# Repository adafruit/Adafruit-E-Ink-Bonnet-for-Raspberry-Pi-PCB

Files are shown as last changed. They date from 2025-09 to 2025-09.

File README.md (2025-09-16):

## Adafruit E-Ink Bonnet for Raspberry Pi - 24-pin E-Paper Displays PCB

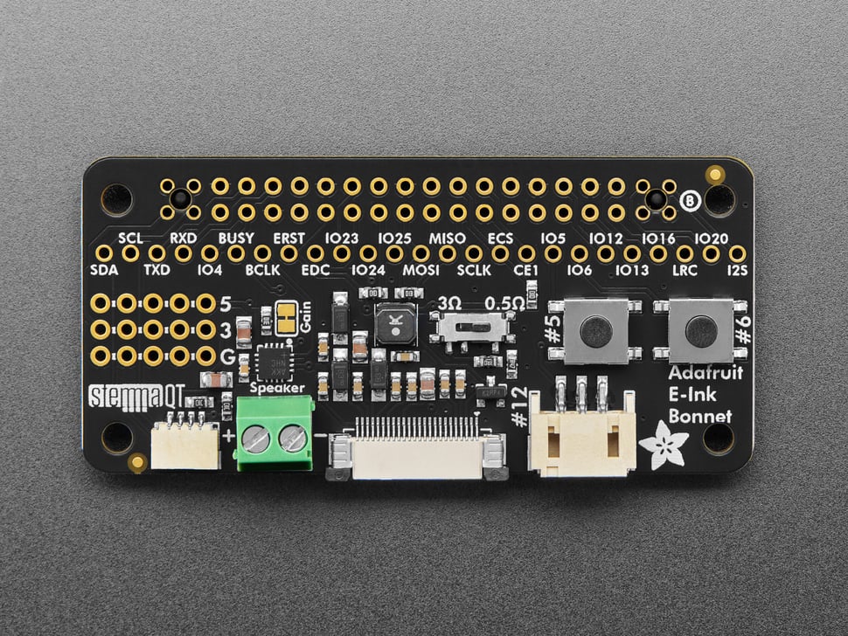
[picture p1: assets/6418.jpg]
<a href="http://www.adafruit.com/products/6418"><br/>
Click here to purchase one from the Adafruit shop</a>

PCB files for the Adafruit E-Ink Bonnet for Raspberry Pi - 24-pin E-Paper Displays. 

Format is EagleCAD schematic and board layout
* https://www.adafruit.com/product/6418

### Description

Easy e-paper finally comes to Raspberry Pi, with this bonnet that's designed to make it a breeze to add any 'standard' pinout 24-pin flex-connector E-Ink display. This add-on handles all the extra components needed to make E-Paper interfacing easy for Pi and Pi-compatible boards. We even include extras like two user buttons, Stemma QT I2C port, and a 3W I2S speaker so you can also have audio playback. Insert your favorite E-Paper display to the connector and you'll have a powerful Linux-powered display for your desk or wall.

Chances are you've seen one of those new-fangled 'e-readers' like the Kindle or Nook. They have gigantic electronic paper 'static' displays - that means the image stays on the display even when power is completely disconnected. The image is also high contrast and very daylight readable. It really does look just like printed paper!

<b>Please note that this does NOT come with the raw display itself</b> - [we stock a wide variety of bare displays](https://www.adafruit.com/product/6396) that will work great. Don't forget to verify that each display needs driver code to match the driver chip. For displays we sell, [we have examples in our E-Ink Python library you can use to craft your own project.](https://github.com/adafruit/Adafruit_CircuitPython_EPD) Often times the E-Paper display has a short cable, in which case [we suggest one of our extender cables.](https://www.adafruit.com/product/4230)

<b>Comes completely pre-assembled and tested</b> so you can plug it in and install our Python code! <b>Works with any Raspberry Pi computer that has a 2x20 connector</b>, such as the Pi B+, Pi 2, Pi 3, Pi 4, Pi 5, and Pi Zero (and any others that have a 2x20 connector!) For installing on Pi's where you need to clear a case or you don't want it against the board, [grab a 2x20 socket riser.](https://www.adafruit.com/product/4079)

Since we had some space on the bonnet we added a [MAX98357 3W 4-8Ω speaker driver](https://www.adafruit.com/product/3006) which has digital I2S input for great sounding audio. This makes it easy to add audio alerts and feedback to your E-Paper projects. [Note you'll have to add a 4-8Ω speaker to the terminal blocks.](https://www.adafruit.com/product/4445)

[On the bottom, we have a Qwiic/STEMMA QT connector for I2C sensors and devices so you can plug and play any of our STEMMA QT devices.](https://www.adafruit.com/?q=stemma%20qt)

<b>To summarize, you will probably want some accessories to build a full project:</b>

* A matching 'bare' E-Paper display with standard 24-pin connector [we stock a wide variety of bare displays here](https://www.adafruit.com/product/6396)
* [One of our extender cables](https://www.adafruit.com/product/4230) so you have plenty of maneuvering room
* [A 4-8Ω speaker](https://www.adafruit.com/product/4445) if you want to use the onboard amplifier
* And of course a Raspberry Pi or other 2x20-connector'd single-board Linux computer!

### License

Adafruit invests time and resources providing this open source design, please support Adafruit and open-source hardware by purchasing products from [Adafruit](https://www.adafruit.com)!

Designed by Limor Fried/Ladyada for Adafruit Industries.

Creative Commons Attribution/Share-Alike, all text above must be included in any redistribution. 
See license.txt for additional details.

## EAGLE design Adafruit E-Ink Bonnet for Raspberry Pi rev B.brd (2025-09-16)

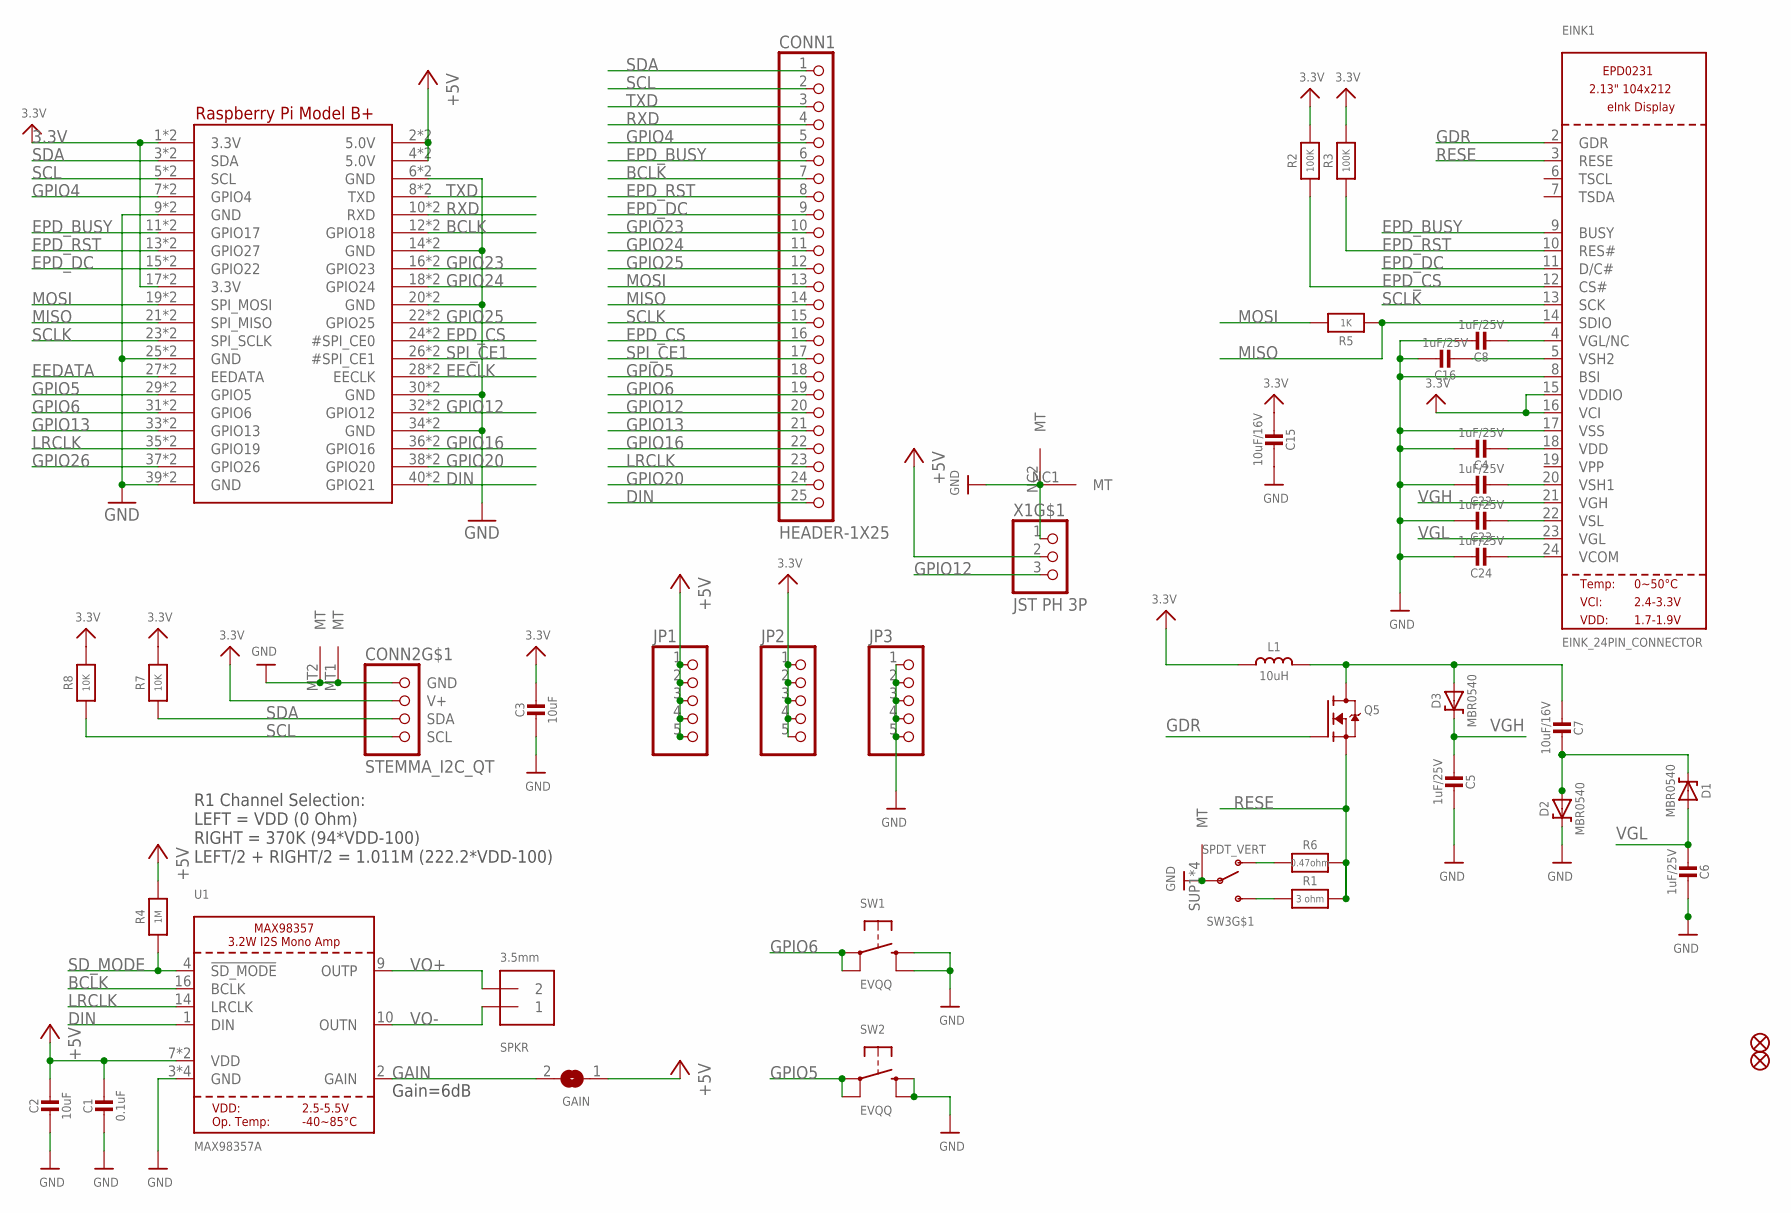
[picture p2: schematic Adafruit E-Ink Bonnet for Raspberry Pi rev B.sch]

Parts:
C1: 0.1uF; 0603-NO
C2, C3: 10uF; 0805-NO
C4, C5, C6, C8, C16, C22, C23, C24: 1uF/25V; 0603-NO
C7, C15: 10uF/16V; 0805-NO
CONN1: HEADER-1X25; 1X25_ROUND_70MIL
CONN2: STEMMA_I2C_QT; JST_SH4
D1, D2, D3: MBR0540; SOD-123
EINK1: EINK_24PIN_CONNECTOR; EINK_24PIN
FID2, FID3: FIDUCIAL_1MM
GAIN: SOLDERJUMPERCLOSED; SOLDERJUMPER_CLOSEDWIRE
JP1, JP2, JP3: HEADER-1X576MIL; 1X05_ROUND_76
L1: 10uH; INDUCTOR_4X4MM_NR401
Q5: IRLML0100; SOT23-3
R1: 3 ohm; 0603-NO
R2, R3: 100K; 0603-NO
R4: 1M; 0603-NO
R5: 1K; 0603-NO
R6: 0.47ohm; 0603-NO
R7, R8: 10K; 0603-NO
RPI1: RASPBERRYPI_BPLUS_BONNET_THMSMT; PI_BONNET_THMSMT
SPKR: 3.5mm; TERMBLOCK_1X2-3.5MM
SW1, SW2: EVQQ; 6MMX6MM_TACTILE_SMT
SW3: SPDT_VERT; SPDT_SMT_SSSS811101
U1: MAX98357A; QFN16_3MM
X1: JST PH 3P; JSTPH3

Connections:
3.3V: C3.1, C15.2, CONN2.2 (V+), EINK1.15 (VDDIO), EINK1.16 (VCI), JP2.1, JP2.2, JP2.3, JP2.4, JP2.5, L1.P$2 (2), R2.2, R3.2, R7.1, R8.1, RPI1.1 (3.3V), RPI1.17 (3.3V), RPI1.S1 (3.3V), RPI1.S17 (3.3V)
+5V: C1.1, C2.1, GAIN.1, JP1.1, JP1.2, JP1.3, JP1.4, JP1.5, R4.2, RPI1.2 (5.0V), RPI1.4 (5.0V), RPI1.S2 (5.0V), RPI1.S4 (5.0V), U1.7 (VDD), U1.8 (VDD), X1.2
BCLK: CONN1.7, RPI1.12 (GPIO18), RPI1.S12 (GPIO18), U1.16 (BCLK)
DIN: CONN1.25, RPI1.40 (GPIO21), RPI1.S40 (GPIO21), U1.1 (DIN)
EECLK: RPI1.28 (EECLK), RPI1.S28 (EECLK)
EEDATA: RPI1.27 (EEDATA), RPI1.S27 (EEDATA)
EPD_BUSY: CONN1.6, EINK1.9 (BUSY), RPI1.11 (GPIO17), RPI1.S11 (GPIO17)
EPD_CS: CONN1.16, EINK1.12 (CS#), R2.1, RPI1.24 (#SPI_CE0), RPI1.S24 (#SPI_CE0)
EPD_DC: CONN1.9, EINK1.11 (D/C#), RPI1.15 (GPIO22), RPI1.S15 (GPIO22)
EPD_RST: CONN1.8, EINK1.10 (RES#), R3.1, RPI1.13 (GPIO27), RPI1.S13 (GPIO27)
GAIN: GAIN.2, U1.2 (GAIN)
GDR: EINK1.2 (GDR), Q5.1 (G)
GND: C1.2, C2.2, C3.2, C4.1, C5.2, C6.2, C8.1, C15.1, C16.1, C22.1, C23.1, C24.1, CONN2.1 (GND), CONN2.MT1 (MT), CONN2.MT2 (MT), D2.C, EINK1.8 (BSI), EINK1.17 (VSS), JP3.1, JP3.2, JP3.3, JP3.4, JP3.5, RPI1.6 (GND), RPI1.9 (GND), RPI1.14 (GND), RPI1.20 (GND), RPI1.25 (GND), RPI1.30 (GND), RPI1.34 (GND), RPI1.39 (GND), RPI1.S6 (GND), RPI1.S9 (GND), RPI1.S14 (GND), RPI1.S20 (GND), RPI1.S25 (GND), RPI1.S30 (GND), RPI1.S34 (GND), RPI1.S39 (GND), SW1.B (S), SW1.B' (S1), SW2.B (S), SW2.B' (S1), SW3.B, SW3.SUP1 (MT), SW3.SUP2 (MT), SW3.SUP3 (MT), SW3.SUP4 (MT), U1.3 (GND), U1.11 (GND), U1.15 (GND), U1.THERMAL (GND), X1.1, X1.NC1 (MT), X1.NC2 (MT)
GPIO4: CONN1.5, RPI1.7 (GPIO4), RPI1.S7 (GPIO4)
GPIO5: CONN1.18, RPI1.29 (GPIO5), RPI1.S29 (GPIO5), SW2.A, SW2.A' (P1)
GPIO6: CONN1.19, RPI1.31 (GPIO6), RPI1.S31 (GPIO6), SW1.A, SW1.A' (P1)
GPIO12: CONN1.20, RPI1.32 (GPIO12), RPI1.S32 (GPIO12), X1.3
GPIO13: CONN1.21, RPI1.33 (GPIO13), RPI1.S33 (GPIO13)
GPIO16: CONN1.22, RPI1.36 (GPIO16), RPI1.S36 (GPIO16)
GPIO20: CONN1.24, RPI1.38 (GPIO20), RPI1.S38 (GPIO20)
GPIO23: CONN1.10, RPI1.16 (GPIO23), RPI1.S16 (GPIO23)
GPIO24: CONN1.11, RPI1.18 (GPIO24), RPI1.S18 (GPIO24)
GPIO25: CONN1.12, RPI1.22 (GPIO25), RPI1.S22 (GPIO25)
GPIO26: RPI1.37 (GPIO26), RPI1.S37 (GPIO26)
LRCLK: CONN1.23, RPI1.35 (GPIO19), RPI1.S35 (GPIO19), U1.14 (LRCLK)
MISO: CONN1.14, EINK1.14 (SDIO), R5.1, RPI1.21 (SPI_MISO), RPI1.S21 (SPI_MISO)
MOSI: CONN1.13, R5.2, RPI1.19 (SPI_MOSI), RPI1.S19 (SPI_MOSI)
unnamed: R1.2, SW3.C (S)
unnamed: C7.2, D1.C, D2.A
unnamed: C7.1, D3.A, L1.P$1 (1), Q5.3 (D)
unnamed: C16.2, EINK1.5 (VSH2)
unnamed: C4.2, EINK1.18 (VDD)
unnamed: C22.2, EINK1.20 (VSH1)
unnamed: R6.2, SW3.A (O)
unnamed: C8.2, EINK1.4 (VGL/NC)
unnamed: C23.2, EINK1.22 (VSL)
unnamed: C24.2, EINK1.24 (VCOM)
RESE: EINK1.3 (RESE), Q5.2 (S), R1.1, R6.1
RXD: CONN1.4, RPI1.10 (RXD), RPI1.S10 (RXD)
SCL: CONN1.2, CONN2.4 (SCL), R8.2, RPI1.5 (SCL), RPI1.S5 (SCL)
SCLK: CONN1.15, EINK1.13 (SCK), RPI1.23 (SPI_SCLK), RPI1.S23 (SPI_SCLK)
SDA: CONN1.1, CONN2.3 (SDA), R7.2, RPI1.3 (SDA), RPI1.S3 (SDA)
SD_MODE: R4.1, U1.4 (!SD_MODE)
SPI_CE1: CONN1.17, RPI1.26 (#SPI_CE1), RPI1.S26 (#SPI_CE1)
TXD: CONN1.3, RPI1.8 (TXD), RPI1.S8 (TXD)
VGH: C5.1, D3.C, EINK1.21 (VGH)
VGL: C6.1, D1.A, EINK1.23 (VGL)
VO+: SPKR.2, U1.9 (OUTP)
VO-: SPKR.1, U1.10 (OUTN)

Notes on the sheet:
R1 Channel Selection: LEFT = VDD (0 Ohm) RIGHT = 370K (94*VDD-100) LEFT/2 + RIGHT/2 = 1.011M (222.2*VDD-100)
Gain=6dB

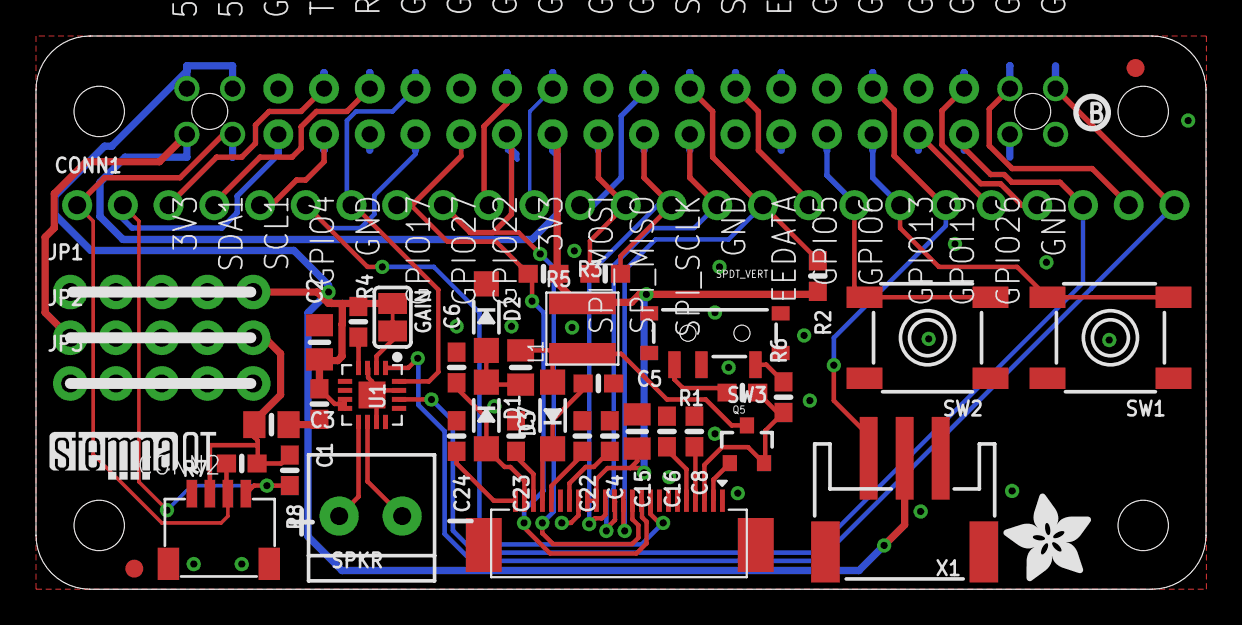
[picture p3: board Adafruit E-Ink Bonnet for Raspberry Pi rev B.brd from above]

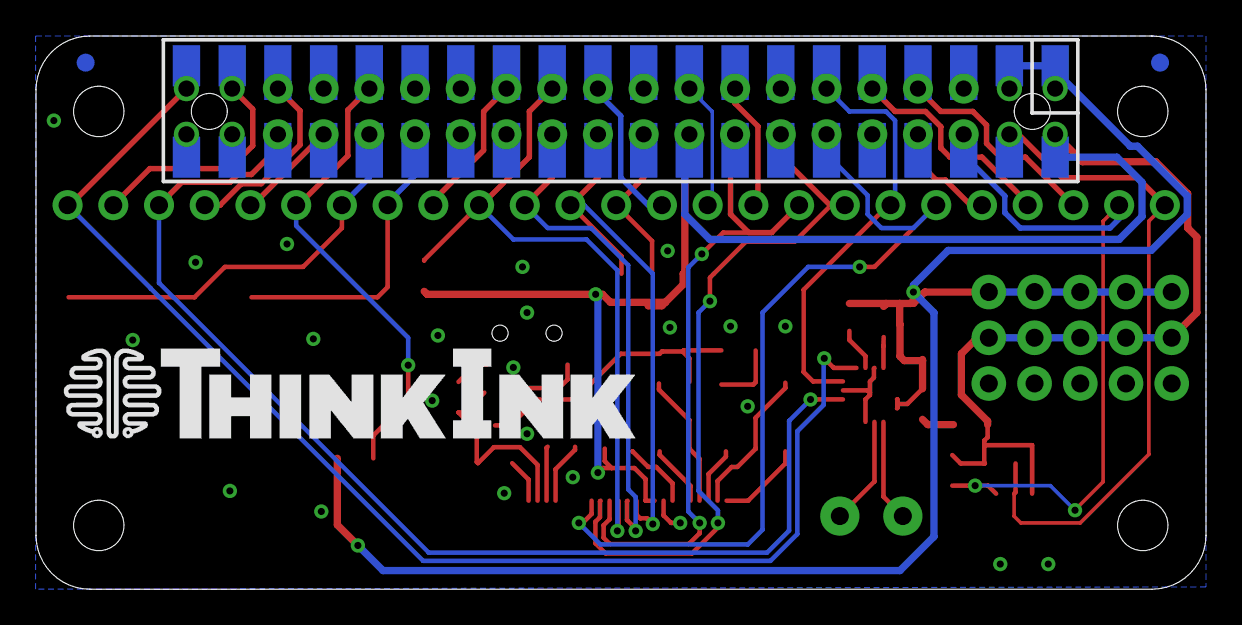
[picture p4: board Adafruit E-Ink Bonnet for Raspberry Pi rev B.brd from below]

Board: 2 copper layers, 65.0 x 30.7 mm, 85 parts (4 on the bottom side), 49 nets.

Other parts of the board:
E$1: THINKINK_1.25IN
PLABEL0: PLABEL0
PLABEL1: PLABEL1
PLABEL2: PLABEL2
PLABEL3: PLABEL3
PLABEL4: PLABEL4
PLABEL5: PLABEL5
PLABEL6: PLABEL6
PLABEL7: PLABEL7
PLABEL8: PLABEL8
PLABEL9: PLABEL9
PLABEL10: PLABEL10
PLABEL11: PLABEL11
PLABEL12: PLABEL12
PLABEL13: PLABEL13
PLABEL14: PLABEL14
PLABEL15: PLABEL15
PLABEL16: PLABEL16
PLABEL17: PLABEL17
PLABEL18: PLABEL18
PLABEL19: PLABEL19
PLABEL20: PLABEL20
PLABEL21: PLABEL21
PLABEL22: PLABEL22
PLABEL23: PLABEL23
PLABEL24: PLABEL24
PLABEL25: PLABEL25
PLABEL26: PLABEL26
PLABEL27: PLABEL27
PLABEL28: PLABEL28
PLABEL29: PLABEL29
PLABEL30: PLABEL30
PLABEL31: PLABEL31
PLABEL32: PLABEL32
PLABEL33: PLABEL33
PLABEL34: PLABEL34
PLABEL35: PLABEL35
PLABEL36: PLABEL36
PLABEL37: PLABEL37
PLABEL38: PLABEL38
U$11: PCBFEAT-REV-040
U$12: ADAFRUIT_5MM
U$24: STEMMAQT

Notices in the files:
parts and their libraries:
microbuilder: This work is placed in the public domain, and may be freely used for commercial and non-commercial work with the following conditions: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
